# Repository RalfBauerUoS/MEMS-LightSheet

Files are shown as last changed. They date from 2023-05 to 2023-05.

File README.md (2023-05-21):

# MEMS-LightSheet
This repository is under construction and currently in development.

In the folders are details about the material list to build an open-top MEMS-Lightsheet microscope as described in this Scientific Report paper: https://www.nature.com/articles/s41598-021-93454-8

Additionally there are 3D-designs, a Labview based control code using either a Thorlabs CS2100M-USB or IDS-3060CP camera and custom electronics details for the control.

## MEMS-LightSheet design
The below 3D-schematic shows the overall setup, excluting the fibre coupled lasers and sample stage.

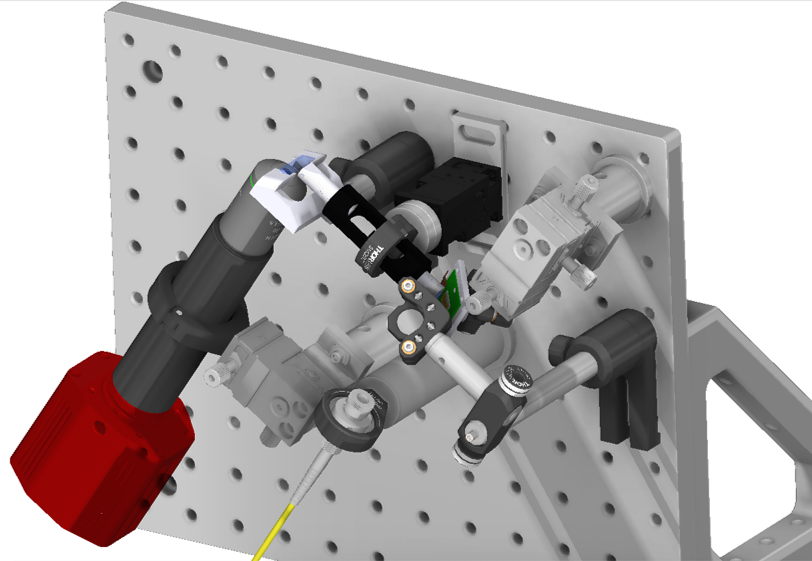
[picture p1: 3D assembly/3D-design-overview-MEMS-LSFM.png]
3D design overview


The 3D parts and full assembly of the shown setup are available in Autodesk Inventor format under [3D design assembly](https://github.com/RalfBauerUoS/MEMS-LightSheet/tree/63631282c4d5373fddde7aa4fce069a93c0868e5/3D%20assembly).

## Part list
The part list and cost (as of September 2021) can be found in [this pdf](https://github.com/RalfBauerUoS/MEMS-LightSheet/blob/63631282c4d5373fddde7aa4fce069a93c0868e5/MEMS-LightSheet_componentListandCost.pdf).

## Electronics
An overview schematics of the electronics required to drive the piezoelectric dual axis MEMS micromirror and 3mm electrical tunable lens can be found [here].

## MEMS control
Details to be added.

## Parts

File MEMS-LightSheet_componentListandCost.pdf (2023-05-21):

List of materials for Miniaturised MEMS-LightSheet system

Item | Manufacturer | Manufacturer number Cost (£)
Breadboard | Thorlabs | MB2530/M | 107
Single mode fibre | Thorlabs | S405-XP-Custom | 125
Fibre collimator | Thorlabs | CFC-2A | 216
Adapter for collimator | Thorlabs | AD15F2 | 23
Lens holder | Thorlabs | LMR1/M | 12
1" post, 3.5" height | Thorlabs | RS3.5P/M | 26
1" post, 1.5" height | Thorlabs | RS1.5P/M | 20
1" post, 2" height | Thorlabs | RS2P/M | 22
1" post clamps x3 | Thorlabs | CF125 | 21
50mm post x2 | Thorlabs | TR50/M | 8
100mm post | Thorlabs | TR100/M | 5
post holder x2 | Thorlabs | UPH40/M | 49
1/2" mirror | Thorlabs | ME05/P01 | 13
1/2" mirror holder | Thorlabs | KM05/M | 30
90deg post braket | Thorlabs | RA90/M | 8
3-axis stage | Newport | M-DS25-XYZ | 258
Adapter for 3-axis stage | Newport | M-B-2C | 35
3-axis stage x2 | Thorlabs | DT12XYZ | 492
1/2" mirror holder | Thorlabs | KM05/M | 30
1/2" lens tube | Thorlabs | SM05L20C | 43
1/2" Lens tube holder | Thorlabs | SM05TC | 32
Adapter plates x2 | Thorlabs | RS5M | 12
1" lens tube | Thorlabs | SM1L40 | 35
1" lens tube holder | Thorlabs | SM1TC | 34
7.5mm lens x2 | Thorlabs | AC050-008-A | 73
30mm lens | Thorlabs | AC127-030-A | 41
x20 objective | Newport | MVC-20X | 98
RMS to 1" adapter | Thorlabs | SM1A3 | 14
tunable lens | Edmund Optics | 37-344 | 106
Emission Filter | Thorlabs | FEL0500 | 60
Camera | Thorlabs | CS2100M-USB | 2379
3D-printed prism | Formlabs | custom | 5
3D-printed adapter | Formlabs | custom | 25
MEMS | Stanley Inc | custom | 85
Arduino Due | Arduino | Due | 31
Drive electronics | custom | custom | 100
| | overall | 4673 (ex VAT)

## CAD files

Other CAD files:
3D assembly/200205 - Holder for MEMS on halfinch mount.ipt
3D assembly/200610 - 7-5mm lens adapter for half inch tube - MEMS side.ipt
3D assembly/200610 - 7-5mm lens adapter for half inch tube - sample side.ipt
3D assembly/200610 - prism holder on post for 33-69deg.ipt
3D assembly/200724 - 33-69 prism.ipt
3D assembly/200724 - Optotune adapter v1.ipt
3D assembly/AC050-008-A-Step.ipt
3D assembly/AC127-030-A-Step.ipt
3D assembly/AD9.5F-Step.ipt
3D assembly/CF125C_M-Step.ipt
3D assembly/CFC-2X-A-Step.ipt
3D assembly/LMR1_M-Step.ipt
3D assembly/MB2530_M-Step_3over2.ipt
3D assembly/ME05-P01-Step.ipt
3D assembly/MEMS.ipt
3D assembly/Newport-M-B-2C.ipt
3D assembly/Newport-M-DS25-XYZ.ipt
3D assembly/Optotune 3mm lens.ipt
3D assembly/P1-460B-FC-1-Step.ipt
3D assembly/PCB.ipt
3D assembly/RA90_M-Step.ipt
3D assembly/RMS20X-PF-Step.ipt
3D assembly/RS1.5P_M-Step.ipt
3D assembly/RS2P_M-Step.ipt
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
